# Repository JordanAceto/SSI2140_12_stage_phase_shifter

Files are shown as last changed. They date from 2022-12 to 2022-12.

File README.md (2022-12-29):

# SSI2140 Phase Shifter

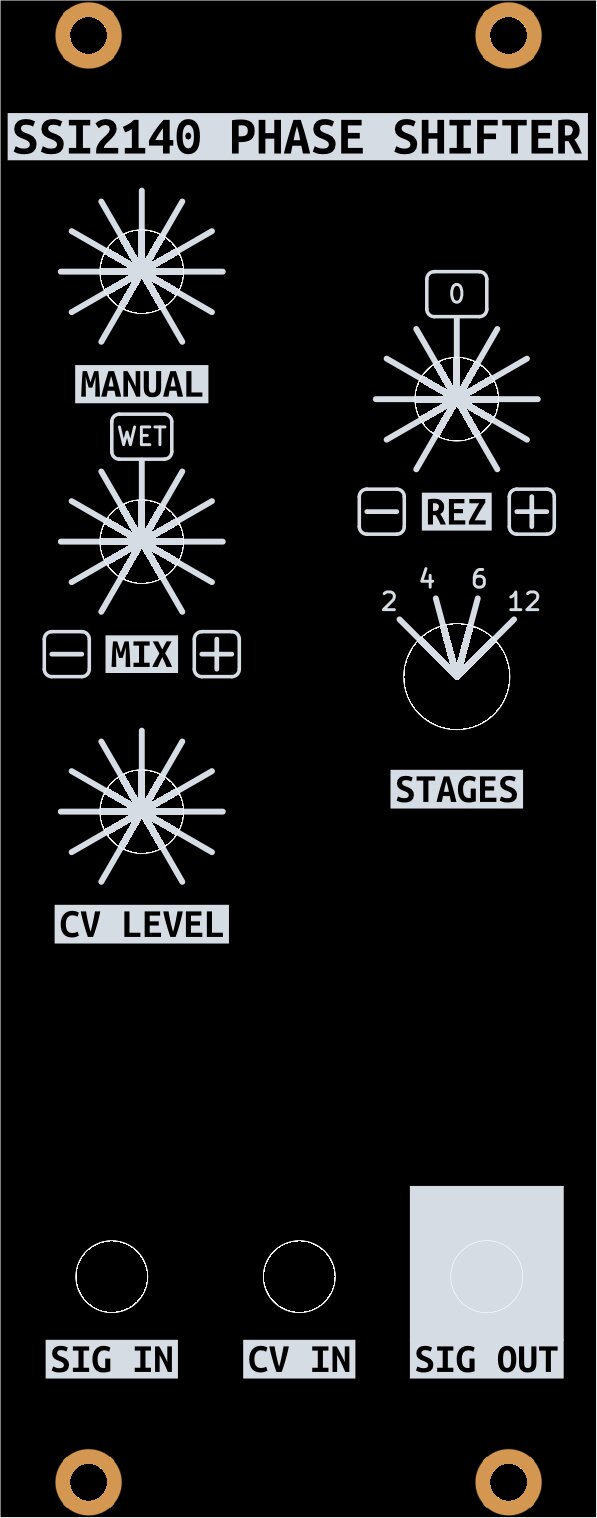
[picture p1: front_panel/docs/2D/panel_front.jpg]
front panel


---

## [SCHEMATIC](https://github.com/JordanAceto/SSI2140_12_stage_phase_shifter/blob/main/main_pcb/docs/SSI2140_phase_shifter-schematic.pdf)

---

### Features
- Eurorack 12 stage phase shifter
- Selectable number of stages (2, 4, 6, and 12)
- Positive and negative feedback
- Positive and negative wet/dry mix
- 1 attenuated CV input with approximately 1V/OCT response

---

## Status of the project:

Task | Status |
---------|--------------|
Schematic capture | &#9745;
PCB layout | &#9745;
Test build | &#9745;
Safe to order boards| &#9745;

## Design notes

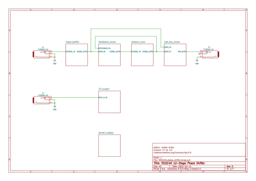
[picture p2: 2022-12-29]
main_pcb/docs/html_nav/images/cat_Schematic_SSI2140_phase_shifter-schematic.png

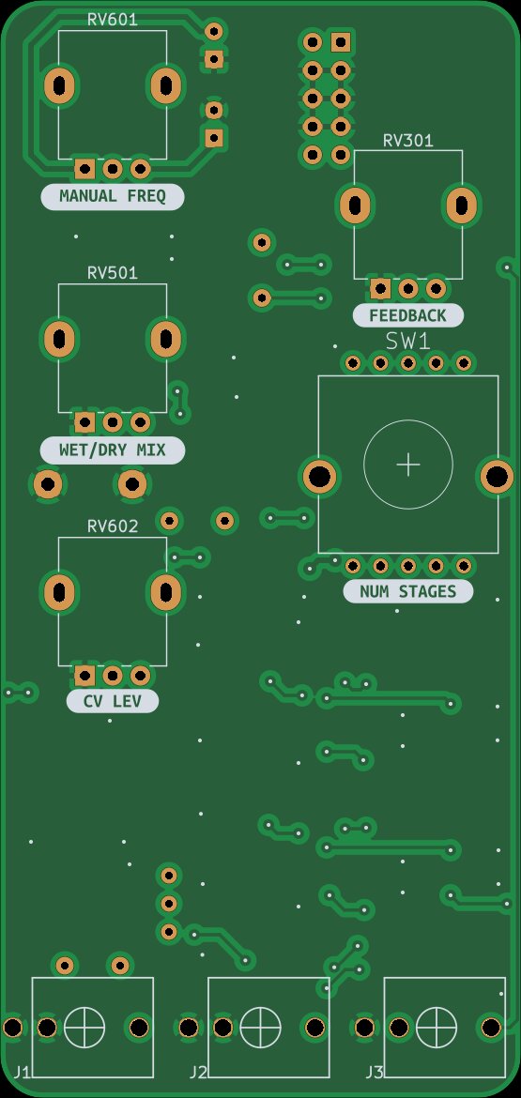
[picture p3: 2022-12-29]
main_pcb/docs/2D/SSI2140_phase_shifter-top.jpg

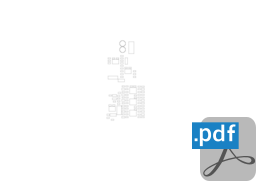
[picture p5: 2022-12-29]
main_pcb/docs/html_nav/images/cat_pdf_layers_SSI2140_phase_shifter-B_Courtyard.png

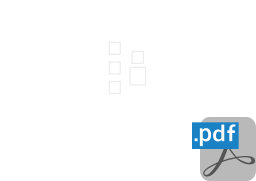
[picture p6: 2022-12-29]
main_pcb/docs/html_nav/images/cat_pdf_layers_SSI2140_phase_shifter-F_Courtyard.png

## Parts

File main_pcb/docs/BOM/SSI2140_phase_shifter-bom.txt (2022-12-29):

Row	Description	Part	References	Value	Footprint	Quantity Per PCB	Status	Datasheet
1	Unpolarized capacitor	C	C301 C303 C501 C503 C601	100p	C_0603_1608Metric	5	 	~
2	Unpolarized capacitor	C	C202	470p	C_0603_1608Metric	1	 	~
3	Unpolarized capacitor	C	C401 C402 C403 C404 C405 C406 C407 C408 C409 C410 C411 C412	1n C0G	C_0805_2012Metric	12	 	~
4	Unpolarized capacitor	C	C302	22n	C_Rect_L7.0mm_W2.5mm_P5.00mm	1	 	~
5	Unpolarized capacitor	C	C502	100n	C_Rect_L7.0mm_W2.5mm_P5.00mm	1	 	~
6	Unpolarized capacitor	C	C703 C704 C705 C706 C707 C708 C709 C710 C711 C712 C713 C714	100n	C_0603_1608Metric	12	 	~
7	Unpolarized capacitor	C	C201	220n	C_Rect_L7.0mm_W2.5mm_P5.00mm	1	 	~
8	Polarized capacitor	C_Polarized	C701 C702	10u	CP_Radial_D6.3mm_P2.50mm	2	 	~
9	Zener diode	D_Zener	D601 D602	5v1	D_SOD-123	2	 	~
10		PJ301M-12	J1 J2 J3	PJ301M-12	PJ301M-12	3	 	
11	Generic connector, double row, 02x05, odd/even pin numbering scheme (row 1 odd numbers, row 2 even numbers), script generated (kicad-library-utils/schlib/autogen/connector/)	Conn_02x05_Odd_Even	J5	power_entry	PinHeader_2x05_P2.54mm_Vertical	1	 	~
12	Resistor	R	R402 R405 R408 R411 R414 R417 R420 R423 R426 R429 R432 R435	200	R_0603_1608Metric	12	 	~
13	Resistor	R	R506	1k	R_0603_1608Metric	1	 	~
14	Resistor	R	R606	3k3	R_0603_1608Metric	1	 	~
15	Resistor	R	R201 R401 R403 R404 R406 R407 R409 R410 R412 R413 R415 R416 R418 R419 R421 R422 R424 R425 R427 R428 R430 R431 R433 R434 R436 R503	10k	R_0603_1608Metric	26	 	~
16	Resistor	R	R504 R607	15k	R_0603_1608Metric	2	 	~
17	Resistor	R	R202 R301 R302 R303 R304 R305 R501 R502 R505 R602 R605	100k	R_0603_1608Metric	11	 	~
18	Resistor	R	R603	270k	R_0603_1608Metric	1	 	~
19	Resistor	R	R604	1M	R_0603_1608Metric	1	 	~
20	Potentiometer	R_Potentiometer	RV301 RV501 RV601 RV602	100k c.d.	Potentiometer_Alpha_RD901F-40-00D_Single_Vertical	4	 	~
21	Trim-potentiometer	R_Potentiometer_Trim	RV603	100k	Potentiometer_Bourns_3296W_Vertical	1	 	~
22	3 rotary switches with 4 positions	SR1712F-0204	SW1	SR1712F-0204	SR1712F_rotary_switch	1	 	
23		SSI2140	U3 U4 U5	SSI2140	TSSOP-20_4.4x6.5mm_P0.65mm	3	 	
24	Dual Low-Noise JFET-Input Operational Amplifiers, DIP-8/SOIC-8	TL072	U1 U2 U6	TL072	SOIC-8_3.9x4.9mm_P1.27mm	3	 	http://www.ti.com/lit/ds/symlink/tl071.pdf

Project info:
Schematic:	SSI2140_phase_shifter
Variant:	default
Revision:	0
Date:	2022-10-11
KiCad Version:	6.0.5+dfsg-1~bpo11+1
Statistics:
Component Groups:	24
Component Count:	108 (87 SMD/ 15 THT)
Fitted Components:	108 (87 SMD/ 15 THT)
Number of PCBs:	1
Total Components:	108

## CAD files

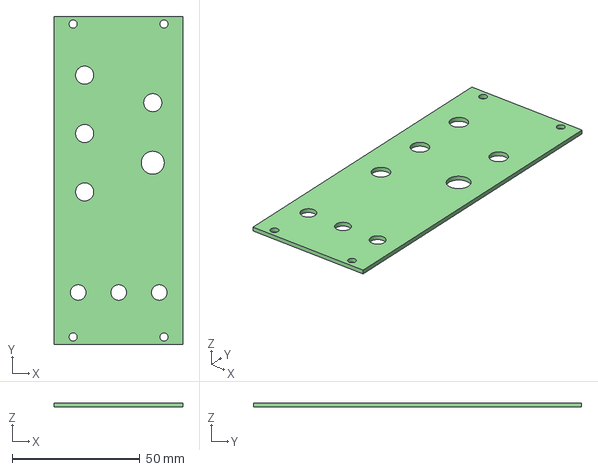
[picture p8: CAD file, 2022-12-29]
front_panel/docs/CAD/SSI2140_Phase_Shifter_front_panel-3D.step
50.5 x 128.5 x 1.60 mm

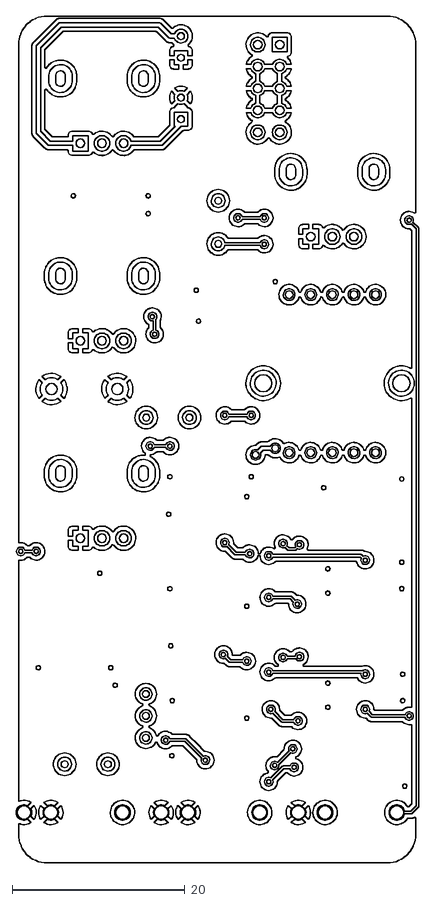
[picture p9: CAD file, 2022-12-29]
main_pcb/docs/CAD/SSI2140_phase_shifter-F_Cu.dxf
46.6 x 98.0

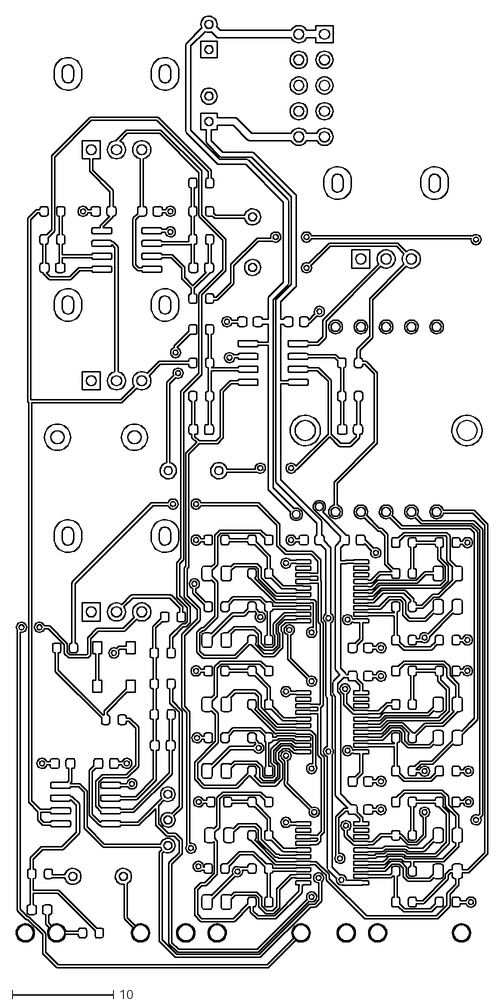
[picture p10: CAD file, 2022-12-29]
main_pcb/docs/CAD/SSI2140_phase_shifter-B_Cu.dxf
46.6 x 94.1

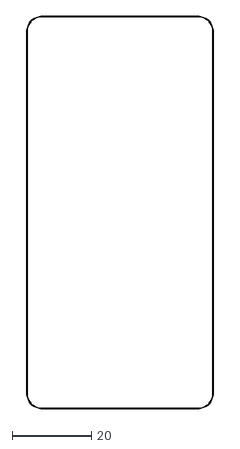
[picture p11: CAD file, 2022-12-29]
main_pcb/docs/CAD/SSI2140_phase_shifter-Edge_Cuts.dxf
47.0 x 99.1

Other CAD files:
main_pcb/docs/CAD/SSI2140_phase_shifter-B_Mask.dxf
main_pcb/docs/CAD/SSI2140_phase_shifter-B_Silkscreen.dxf
main_pcb/docs/CAD/SSI2140_phase_shifter-F_Mask.dxf
main_pcb/docs/CAD/SSI2140_phase_shifter-F_Silkscreen.dxf

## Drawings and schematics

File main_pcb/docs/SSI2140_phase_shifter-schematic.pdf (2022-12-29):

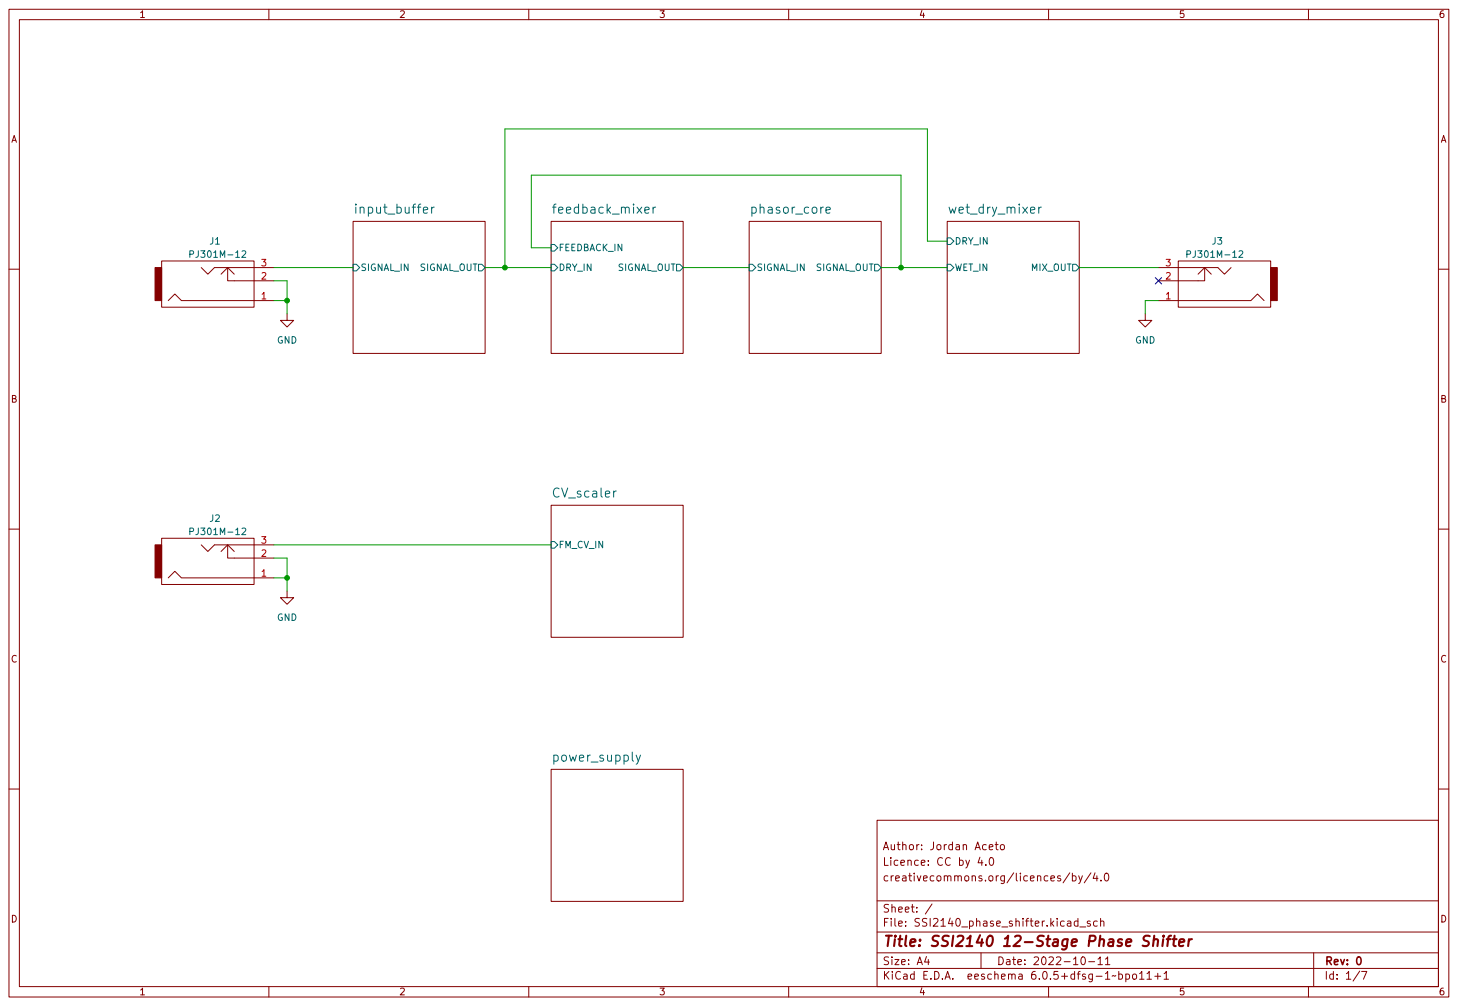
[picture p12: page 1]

Licence: CC by 4.0 Author: Jordan Aceto

File: SSI2140_phase_shifter.kicad_sch Sheet: / creativecommons.org/licences/by/4.0

Id: 1/7 Title: SSI2140 12-Stage Phase Shifter

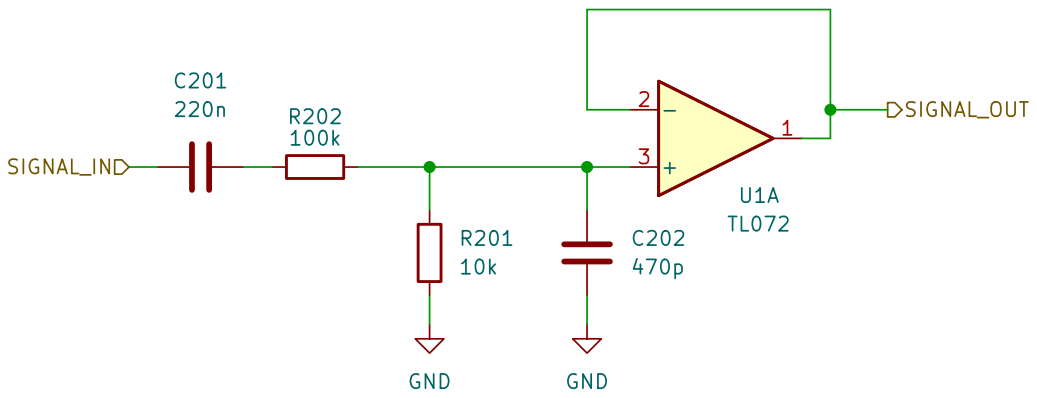
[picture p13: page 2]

Licence: CC by 4.0 Author: Jordan Aceto C201

creativecommons.org/licences/by/4.0

Sheet: /input_buffer/
File: input_buffer.kicad_sch
Id: 2/7 Title: SSI2140 12-Stage Phase Shifter

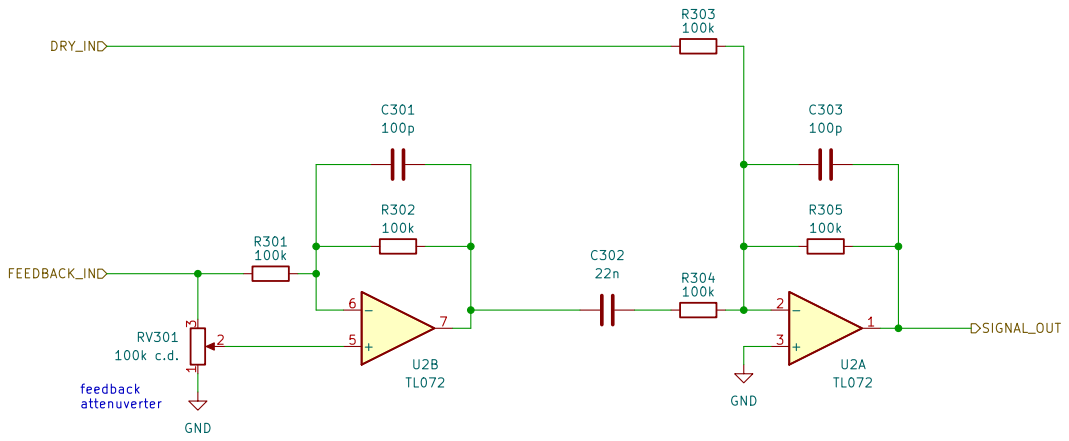
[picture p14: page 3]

Licence: CC by 4.0 Author: Jordan Aceto GND

creativecommons.org/licences/by/4.0

Sheet: /feedback_mixer/
File: feedback_mixer.kicad_sch
Id: 3/7 Title: SSI2140 12-Stage Phase Shifter

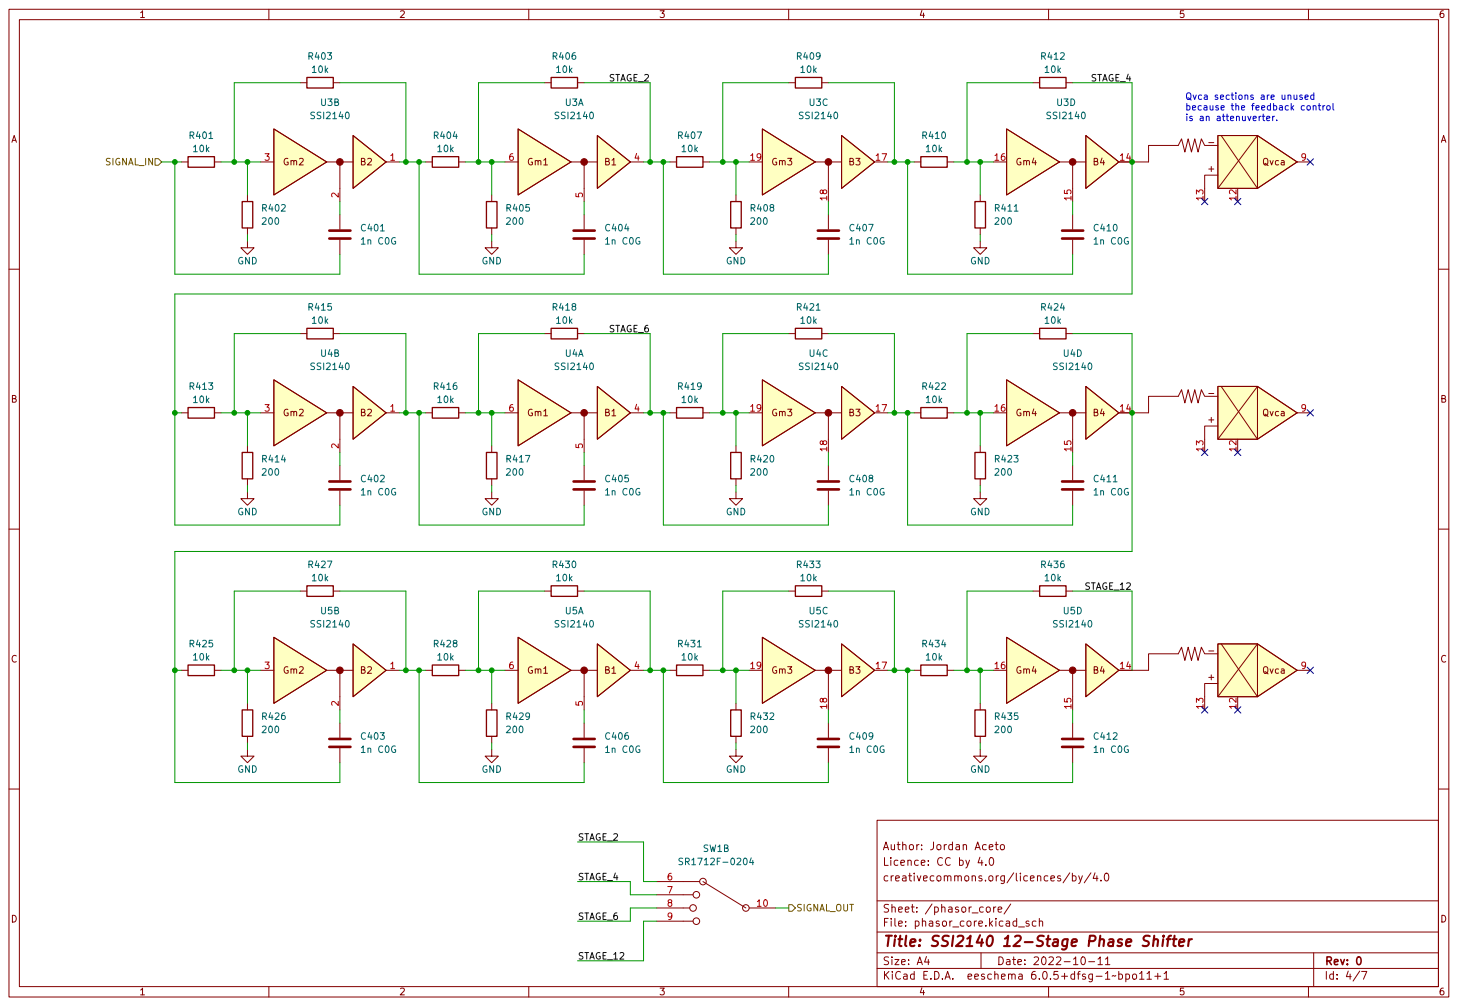
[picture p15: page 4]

because the feedback control
is an attenuverter.

Licence: CC by 4.0 Author: Jordan Aceto GND GND

creativecommons.org/licences/by/4.0

Sheet: /phasor_core/
File: phasor_core.kicad_sch
Id: 4/7 Title: SSI2140 12-Stage Phase Shifter

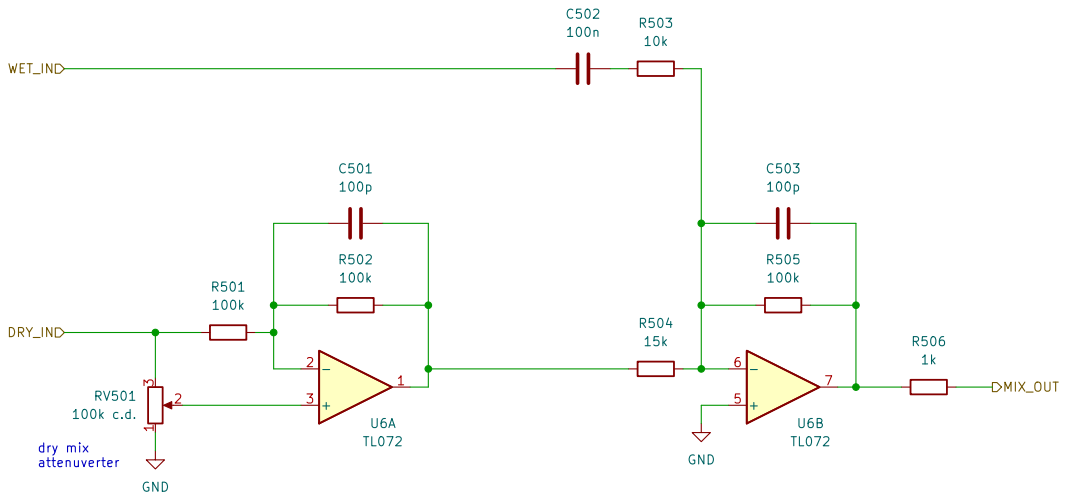
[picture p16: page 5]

Licence: CC by 4.0 Author: Jordan Aceto GND

creativecommons.org/licences/by/4.0

Sheet: /wet_dry_mixer/
File: wet_dry_mixer.kicad_sch
Id: 5/7 Title: SSI2140 12-Stage Phase Shifter

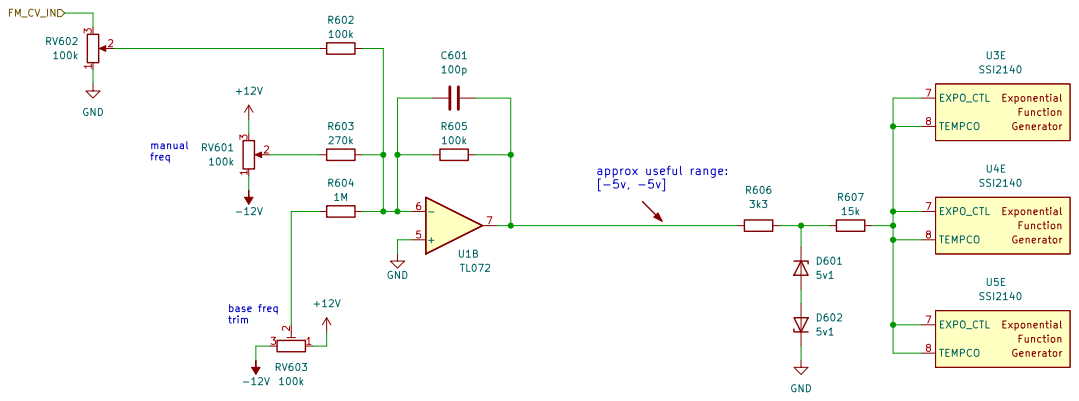
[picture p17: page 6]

creativecommons.org/licences/by/4.0

Sheet: /CV_scaler/
File: CV_scalers.kicad_sch
Id: 6/7 Title: SSI2140 12-Stage Phase Shifter

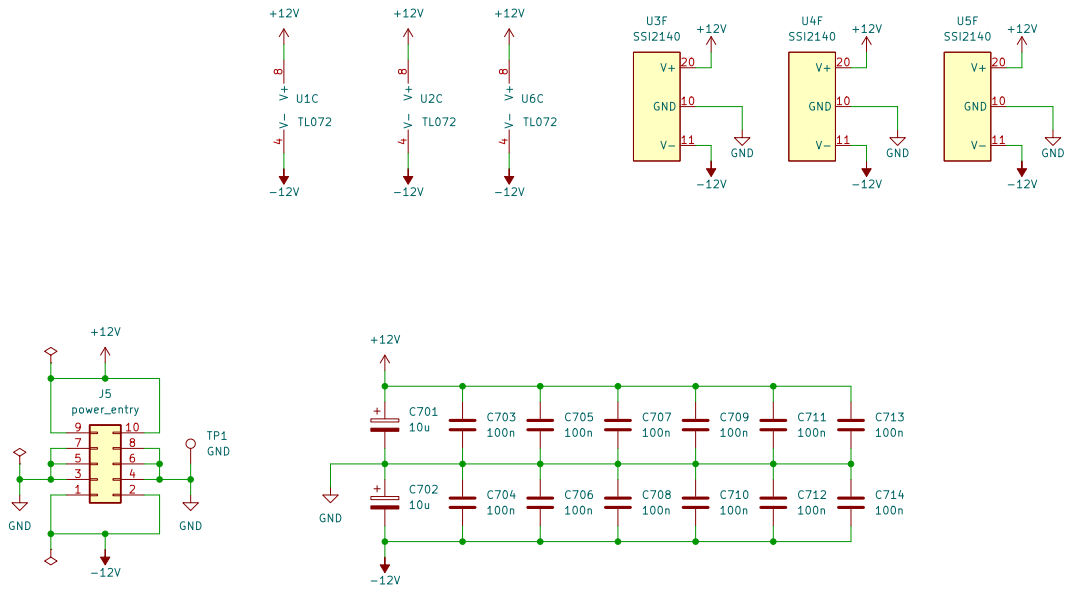
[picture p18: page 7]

Licence: CC by 4.0 Author: Jordan Aceto

creativecommons.org/licences/by/4.0

Sheet: /power_supply/
File: power_supply.kicad_sch
Id: 7/7 Title: SSI2140 12-Stage Phase Shifter

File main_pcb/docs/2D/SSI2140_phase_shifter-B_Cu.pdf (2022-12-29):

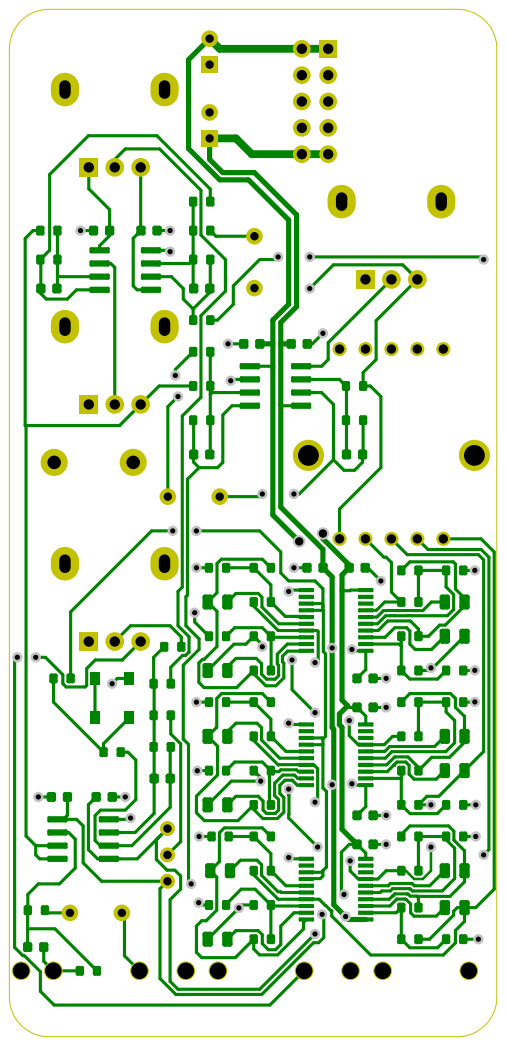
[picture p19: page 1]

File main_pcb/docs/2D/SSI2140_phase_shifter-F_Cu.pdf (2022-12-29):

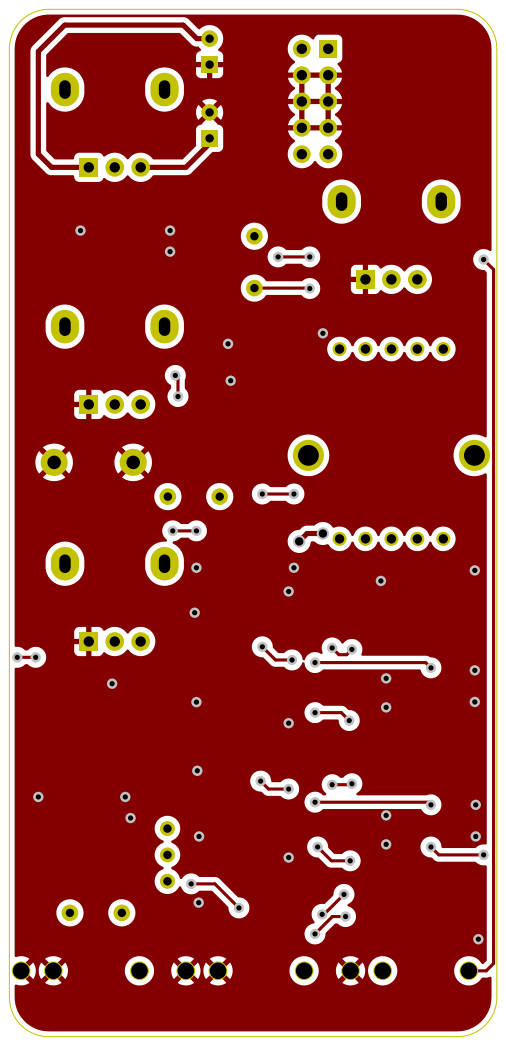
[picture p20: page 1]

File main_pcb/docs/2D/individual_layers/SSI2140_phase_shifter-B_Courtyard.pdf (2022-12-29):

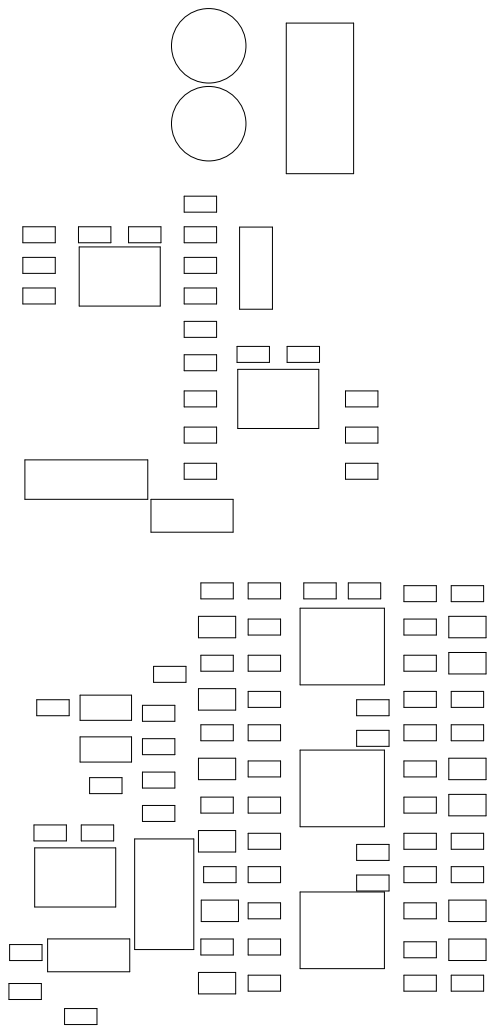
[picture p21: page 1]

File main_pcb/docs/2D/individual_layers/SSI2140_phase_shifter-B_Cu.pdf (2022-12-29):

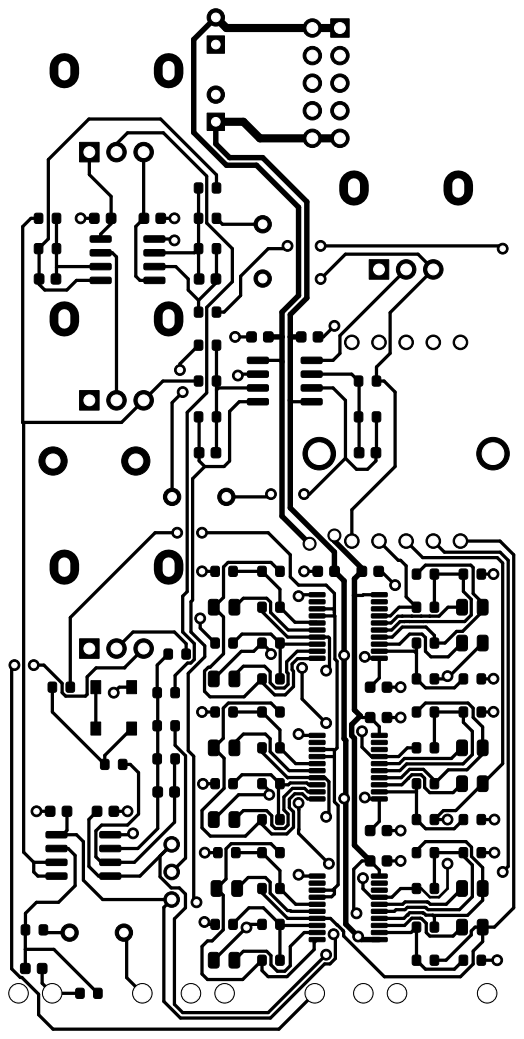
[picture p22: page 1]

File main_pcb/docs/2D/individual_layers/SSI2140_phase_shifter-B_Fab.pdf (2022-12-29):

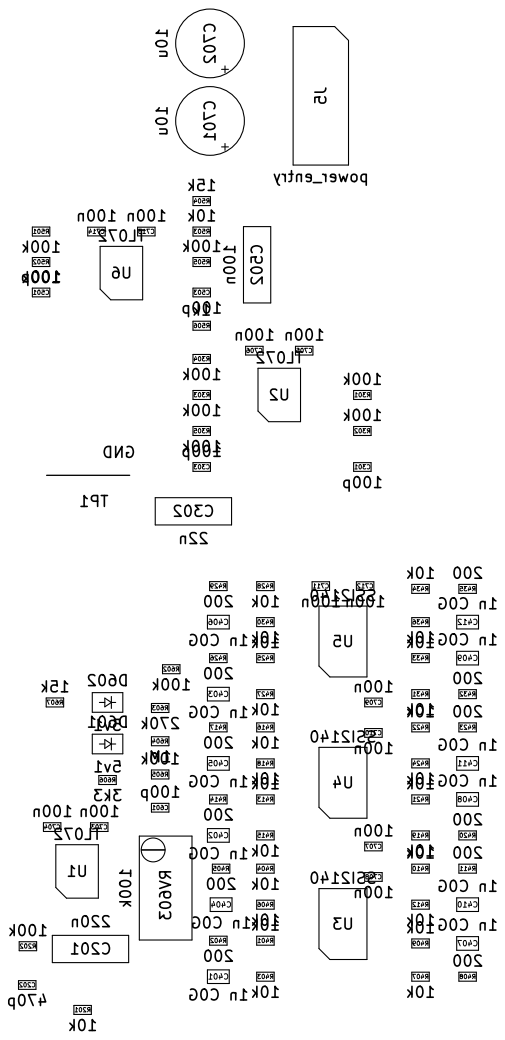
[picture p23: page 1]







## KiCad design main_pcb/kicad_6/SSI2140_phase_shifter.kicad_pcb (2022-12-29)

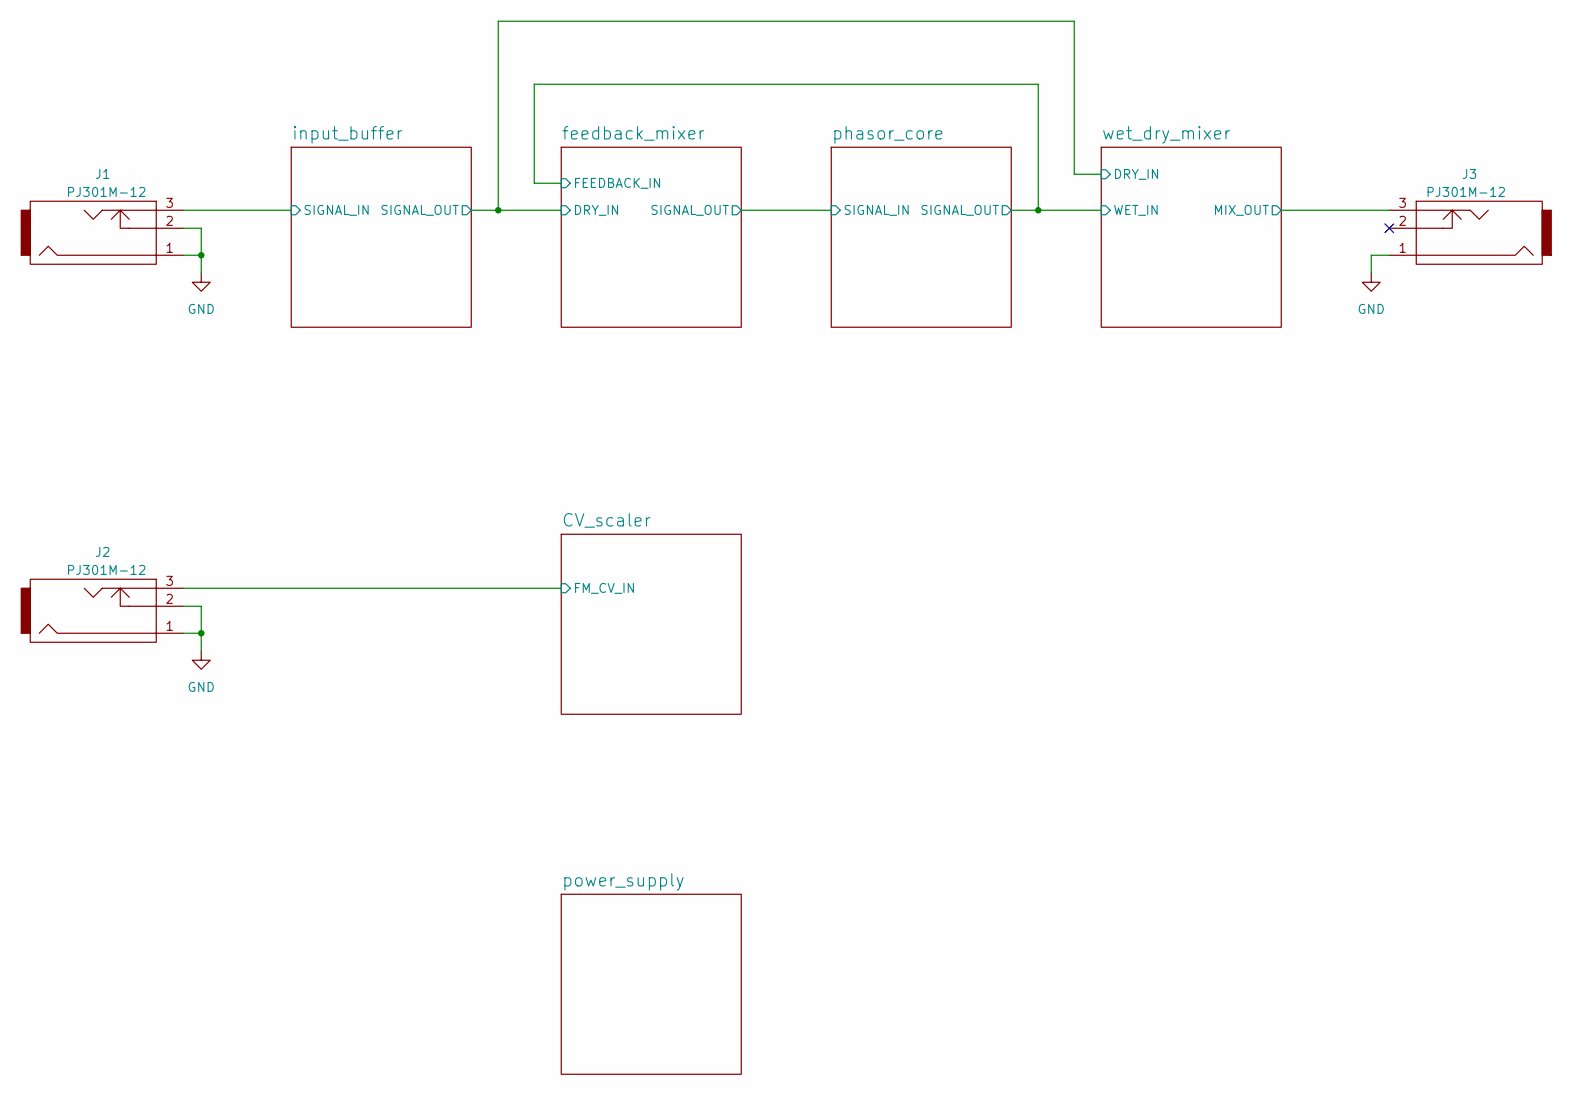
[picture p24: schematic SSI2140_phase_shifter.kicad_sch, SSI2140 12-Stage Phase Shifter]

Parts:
J1, J2, J3: PJ301M-12

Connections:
/CV_scaler/FM_CV_IN: J2.3; also elsewhere on the board
/input_buffer/SIGNAL_IN: J1.3; also elsewhere on the board
/wet_dry_mixer/MIX_OUT: J3.3; also elsewhere on the board
GND: J1.1, J1.2, J2.1, J2.2, J3.1; also elsewhere on the board

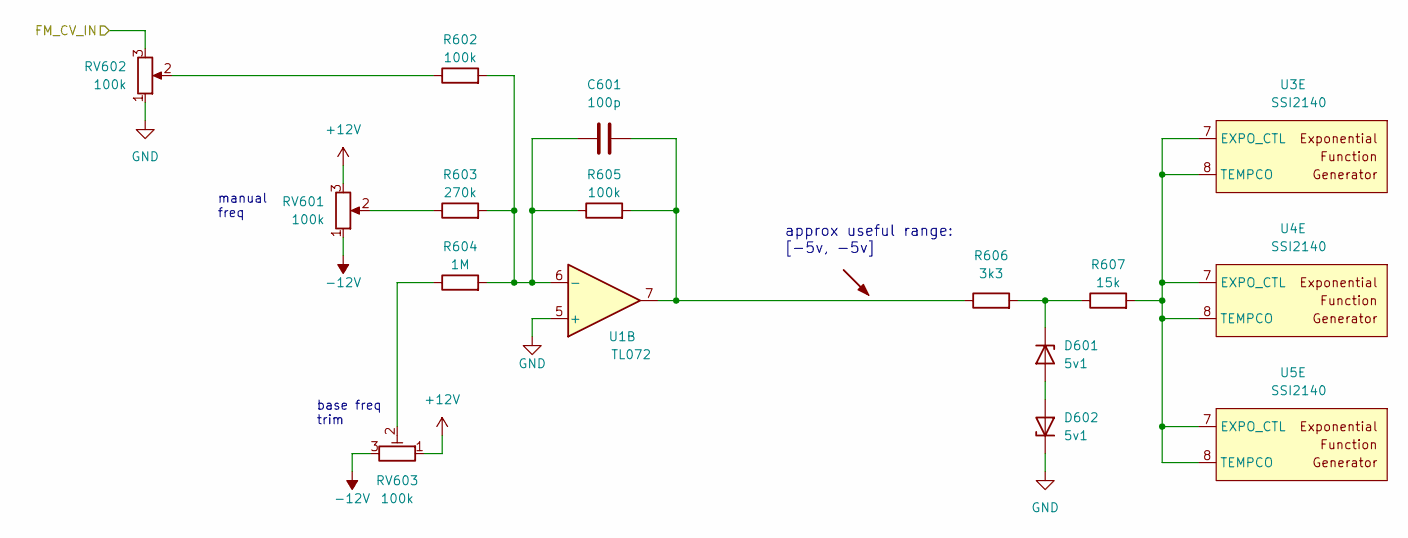
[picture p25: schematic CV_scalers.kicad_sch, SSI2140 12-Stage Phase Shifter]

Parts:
C601: 100p; C_0603_1608Metric
D601, D602: 5v1; D_SOD-123
R602, R605: 100k; R_0603_1608Metric
R603: 270k; R_0603_1608Metric
R604: 1M; R_0603_1608Metric
R606: 3k3; R_0603_1608Metric
R607: 15k; R_0603_1608Metric
RV601, RV602: 100k; Potentiometer_Alpha_RD901F-40-00D_Single_Vertical
RV603: 100k; Potentiometer_Bourns_3296W_Vertical
U1: TL072; SOIC-8_3.9x4.9mm_P1.27mm
U3, U4, U5: SSI2140; TSSOP-20_4.4x6.5mm_P0.65mm

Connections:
+12V: RV601.3, RV603.1; also elsewhere on the board
-12V: RV601.1, RV603.3; also elsewhere on the board
/CV_scaler/FM_CV_IN: RV602.3; also elsewhere on the board
GND: D602.1 (K), RV602.1, U1.5 (+); also elsewhere on the board
unnamed: C601.1, R602.2, R603.2, R604.2, R605.1, U1.6 (-)
unnamed: C601.2, R605.2, R606.1, U1.7
unnamed: D601.1 (K), R606.2, R607.1
unnamed: D601.2 (A), D602.2 (A)
unnamed: R602.1, RV602.2
unnamed: R603.1, RV601.2
unnamed: R604.1, RV603.2
unnamed: R607.2, U3.7 (EXPO_CTL), U3.8 (TEMPCO), U4.7 (EXPO_CTL), U4.8 (TEMPCO), U5.7 (EXPO_CTL), U5.8 (TEMPCO)

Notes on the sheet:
base freq trim
manual freq
approx useful range: [-5v, -5v]

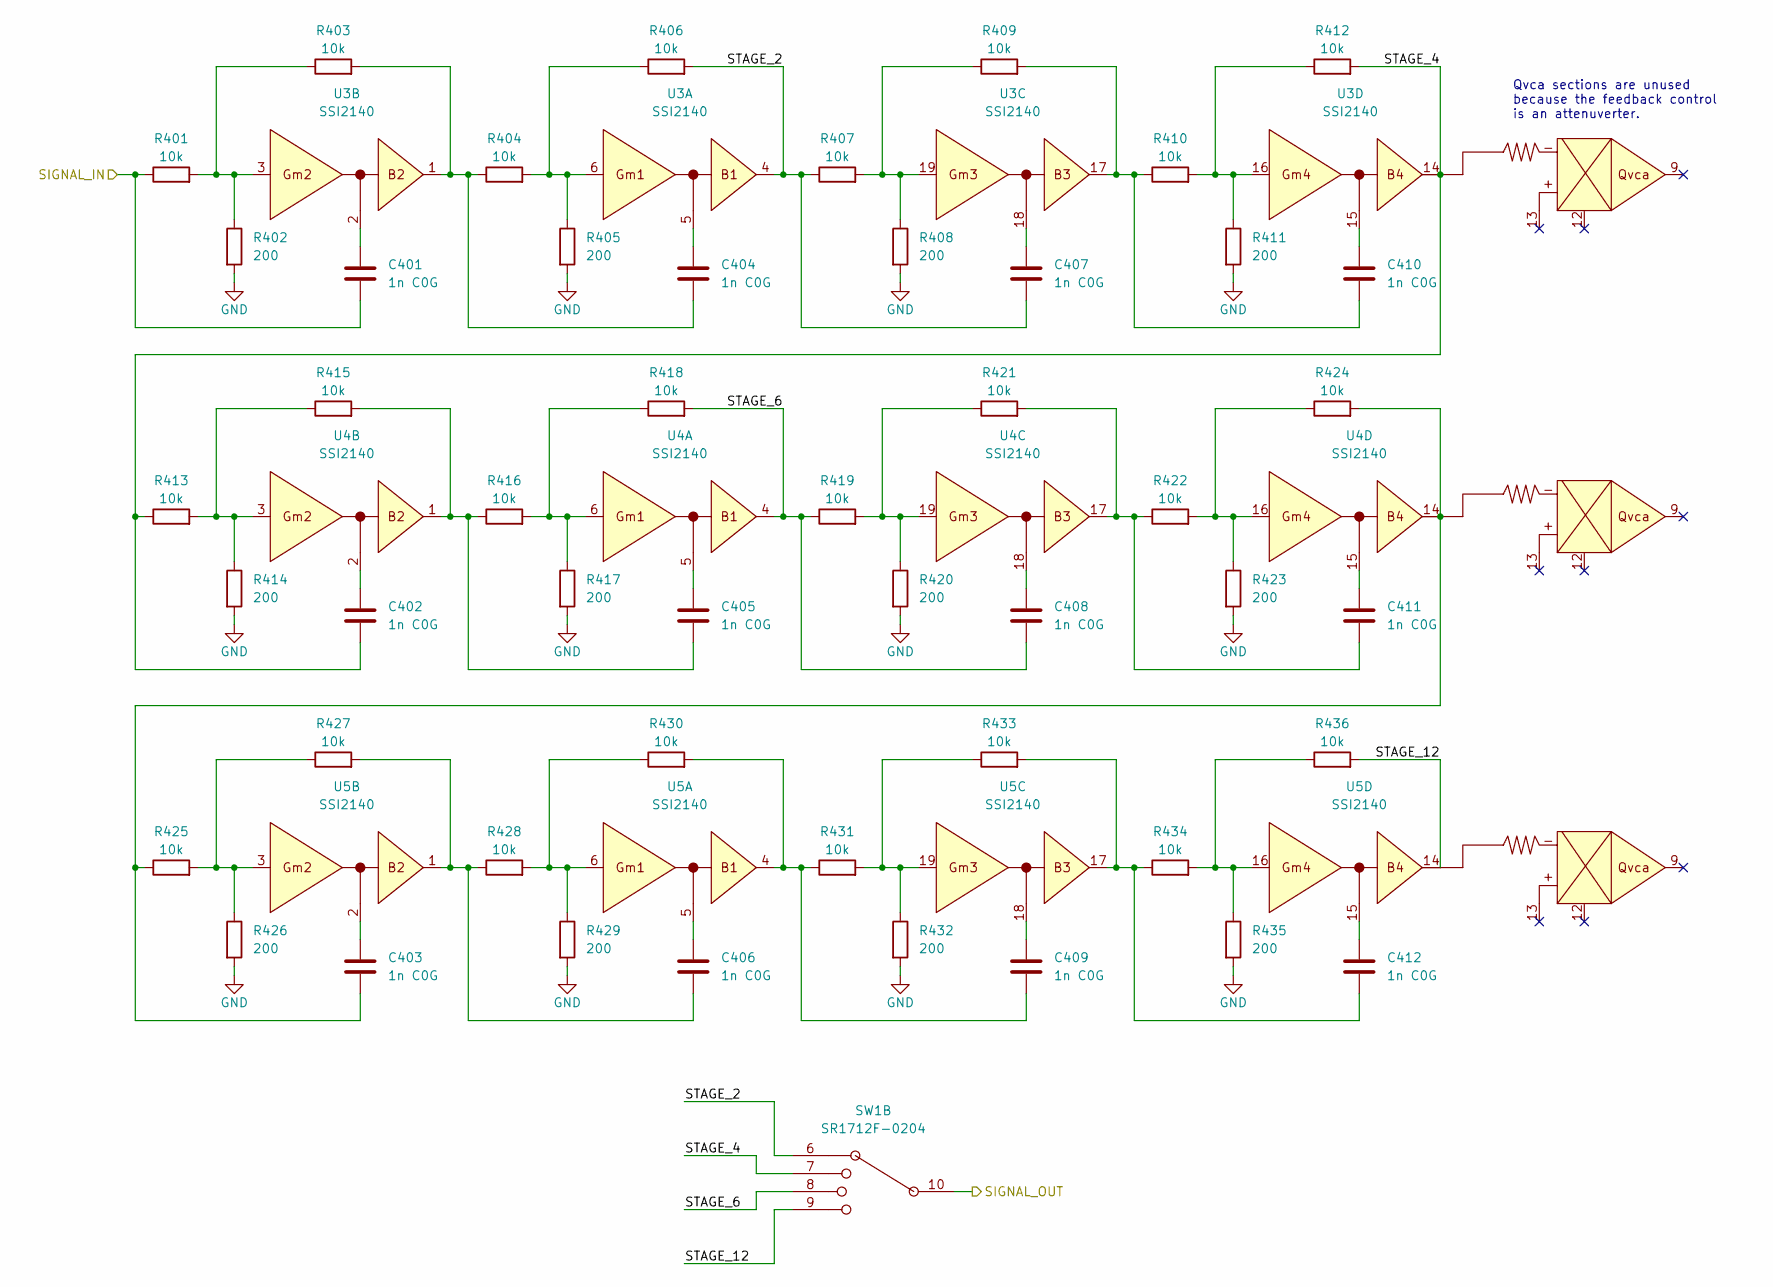
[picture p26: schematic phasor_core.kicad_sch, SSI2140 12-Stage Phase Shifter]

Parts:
C401, C402, C403, C404, C405, C406, C407, C408, C409, C410, C411, C412: 1n C0G; C_0805_2012Metric
R401, R403, R404, R406, R407, R409, R410, R412, R413, R415, R416, R418, R419, R421, R422, R424, R425, R427, R428, R430, R431, R433, R434, R436: 10k; R_0603_1608Metric
R402, R405, R408, R411, R414, R417, R420, R423, R426, R429, R432, R435: 200; R_0603_1608Metric
SW1: SR1712F-0204; SR1712F_rotary_switch
U3, U4, U5: SSI2140; TSSOP-20_4.4x6.5mm_P0.65mm

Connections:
/feedback_mixer/FEEDBACK_IN: SW1.10; also elsewhere on the board
/feedback_mixer/SIGNAL_OUT: C401.2, R401.1; also elsewhere on the board
/phasor_core/STAGE_2: C407.2, R406.2, R407.1, SW1.6, U3.4
/phasor_core/STAGE_4: C402.2, R412.2, R413.1, SW1.7, U3.14
/phasor_core/STAGE_6: C408.2, R418.2, R419.1, SW1.8, U4.4
/phasor_core/STAGE_12: R436.2, SW1.9, U5.14
GND: R402.2, R405.2, R408.2, R411.2, R414.2, R417.2, R420.2, R423.2, R426.2, R429.2, R432.2, R435.2; also elsewhere on the board
unnamed: C401.1, U3.2
unnamed: C402.1, U4.2
unnamed: C403.1, U5.2
unnamed: C403.2, R424.2, R425.1, U4.14
unnamed: C404.1, U3.5
unnamed: C404.2, R403.2, R404.1, U3.1
unnamed: C405.1, U4.5
unnamed: C405.2, R415.2, R416.1, U4.1
unnamed: C406.1, U5.5
unnamed: C406.2, R427.2, R428.1, U5.1
unnamed: C407.1, U3.18
unnamed: C408.1, U4.18
unnamed: C409.1, U5.18
unnamed: C409.2, R430.2, R431.1, U5.4
unnamed: C410.1, U3.15
unnamed: C410.2, R409.2, R410.1, U3.17
unnamed: C411.1, U4.15
unnamed: C411.2, R421.2, R422.1, U4.17
unnamed: C412.1, U5.15
unnamed: C412.2, R433.2, R434.1, U5.17
unnamed: R401.2, R402.1, R403.1, U3.3
unnamed: R404.2, R405.1, R406.1, U3.6
unnamed: R407.2, R408.1, R409.1, U3.19
unnamed: R410.2, R411.1, R412.1, U3.16
unnamed: R413.2, R414.1, R415.1, U4.3
unnamed: R416.2, R417.1, R418.1, U4.6
unnamed: R419.2, R420.1, R421.1, U4.19
unnamed: R422.2, R423.1, R424.1, U4.16
unnamed: R425.2, R426.1, R427.1, U5.3
unnamed: R428.2, R429.1, R430.1, U5.6
unnamed: R431.2, R432.1, R433.1, U5.19
unnamed: R434.2, R435.1, R436.1, U5.16

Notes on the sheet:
Qvca sections are unused because the feedback control is an attenuverter.

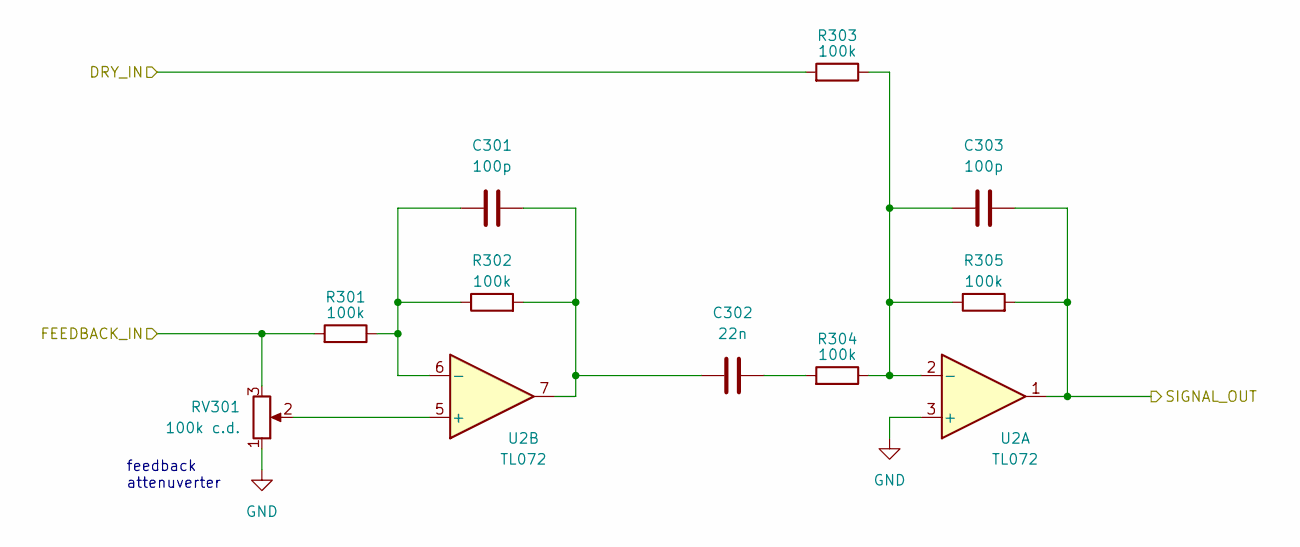
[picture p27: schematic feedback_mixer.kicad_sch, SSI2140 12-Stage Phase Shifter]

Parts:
C301, C303: 100p; C_0603_1608Metric
C302: 22n; C_Rect_L7.0mm_W2.5mm_P5.00mm
R301, R302, R303, R304, R305: 100k; R_0603_1608Metric
RV301: 100k c.d.; Potentiometer_Alpha_RD901F-40-00D_Single_Vertical
U2: TL072; SOIC-8_3.9x4.9mm_P1.27mm

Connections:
/feedback_mixer/DRY_IN: R303.2; also elsewhere on the board
/feedback_mixer/FEEDBACK_IN: R301.2, RV301.3; also elsewhere on the board
/feedback_mixer/SIGNAL_OUT: C303.1, R305.2, U2.1; also elsewhere on the board
GND: RV301.1, U2.3 (+); also elsewhere on the board
unnamed: C301.1, C302.1, R302.2, U2.7
unnamed: C301.2, R301.1, R302.1, U2.6 (-)
unnamed: C302.2, R304.2
unnamed: C303.2, R303.1, R304.1, R305.1, U2.2 (-)
unnamed: RV301.2, U2.5 (+)

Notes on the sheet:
feedback attenuverter

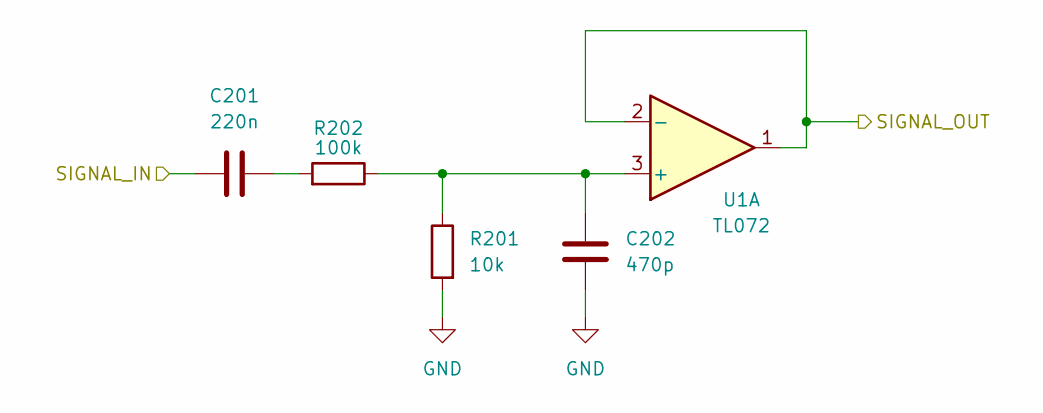
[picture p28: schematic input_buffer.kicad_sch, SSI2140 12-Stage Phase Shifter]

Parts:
C201: 220n; C_Rect_L7.0mm_W2.5mm_P5.00mm
C202: 470p; C_0603_1608Metric
R201: 10k; R_0603_1608Metric
R202: 100k; R_0603_1608Metric
U1: TL072; SOIC-8_3.9x4.9mm_P1.27mm

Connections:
/feedback_mixer/DRY_IN: U1.1, U1.2 (-); also elsewhere on the board
/input_buffer/SIGNAL_IN: C201.2; also elsewhere on the board
GND: C202.1, R201.2; also elsewhere on the board
unnamed: C201.1, R202.2
unnamed: C202.2, R201.1, R202.1, U1.3 (+)

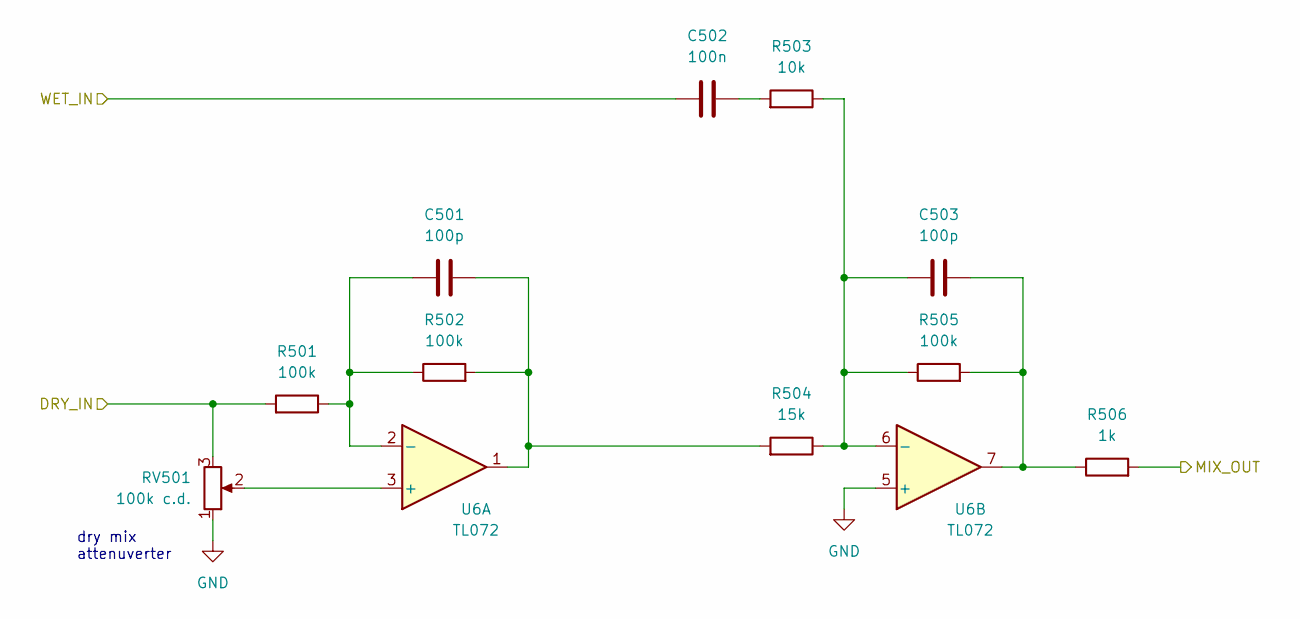
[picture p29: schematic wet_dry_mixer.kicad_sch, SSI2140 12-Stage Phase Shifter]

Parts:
C501, C503: 100p; C_0603_1608Metric
C502: 100n; C_Rect_L7.0mm_W2.5mm_P5.00mm
R501, R502, R505: 100k; R_0603_1608Metric
R503: 10k; R_0603_1608Metric
R504: 15k; R_0603_1608Metric
R506: 1k; R_0603_1608Metric
RV501: 100k c.d.; Potentiometer_Alpha_RD901F-40-00D_Single_Vertical
U6: TL072; SOIC-8_3.9x4.9mm_P1.27mm

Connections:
/feedback_mixer/DRY_IN: R501.2, RV501.3; also elsewhere on the board
/feedback_mixer/FEEDBACK_IN: C502.1; also elsewhere on the board
/wet_dry_mixer/MIX_OUT: R506.2; also elsewhere on the board
GND: RV501.1, U6.5 (+); also elsewhere on the board
unnamed: C501.1, R502.2, R504.2, U6.1
unnamed: C501.2, R501.1, R502.1, U6.2 (-)
unnamed: C502.2, R503.2
unnamed: C503.1, R505.2, R506.1, U6.7
unnamed: C503.2, R503.1, R504.1, R505.1, U6.6 (-)
unnamed: RV501.2, U6.3 (+)

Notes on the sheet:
dry mix attenuverter

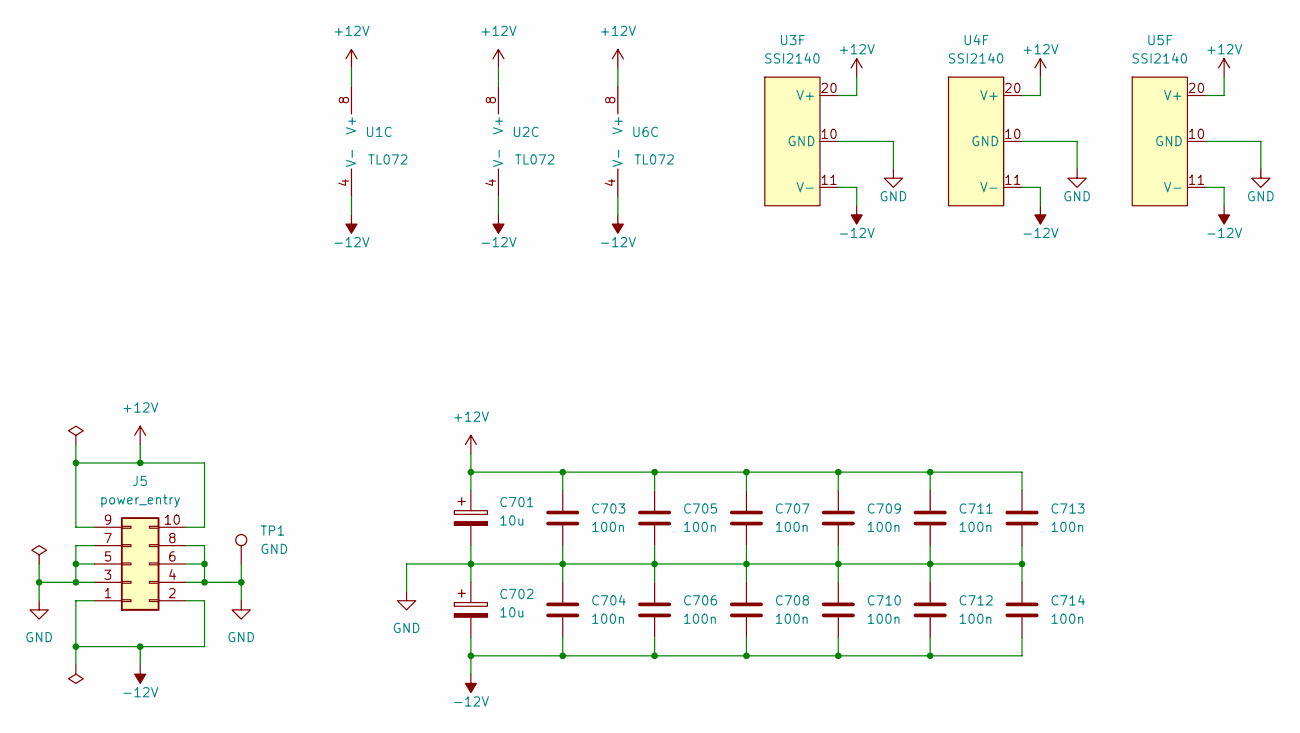
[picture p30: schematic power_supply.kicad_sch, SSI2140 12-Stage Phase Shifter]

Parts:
C701, C702: 10u; CP_Radial_D6.3mm_P2.50mm
C703, C704, C705, C706, C707, C708, C709, C710, C711, C712, C713, C714: 100n; C_0603_1608Metric
J5: power_entry; PinHeader_2x05_P2.54mm_Vertical
TP1: GND; TestPoint_Bridge_Pitch7.62mm_Drill1.3mm
U1, U2, U6: TL072; SOIC-8_3.9x4.9mm_P1.27mm
U3, U4, U5: SSI2140; TSSOP-20_4.4x6.5mm_P0.65mm

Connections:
+12V: C701.1, C703.1, C705.1, C707.1, C709.1, C711.1, C713.1, J5.9, J5.10, U1.8 (V+), U2.8 (V+), U3.20 (V+), U4.20 (V+), U5.20 (V+), U6.8 (V+); also elsewhere on the board
-12V: C702.2, C704.2, C706.2, C708.2, C710.2, C712.2, C714.2, J5.1, J5.2, U1.4 (V-), U2.4 (V-), U3.11 (V-), U4.11 (V-), U5.11 (V-), U6.4 (V-); also elsewhere on the board
GND: C701.2, C702.1, C703.2, C704.1, C705.2, C706.1, C707.2, C708.1, C709.2, C710.1, C711.2, C712.1, C713.2, C714.1, J5.3, J5.4, J5.5, J5.6, J5.7, J5.8, TP1.1, U3.10 (GND), U4.10 (GND), U5.10 (GND); also elsewhere on the board

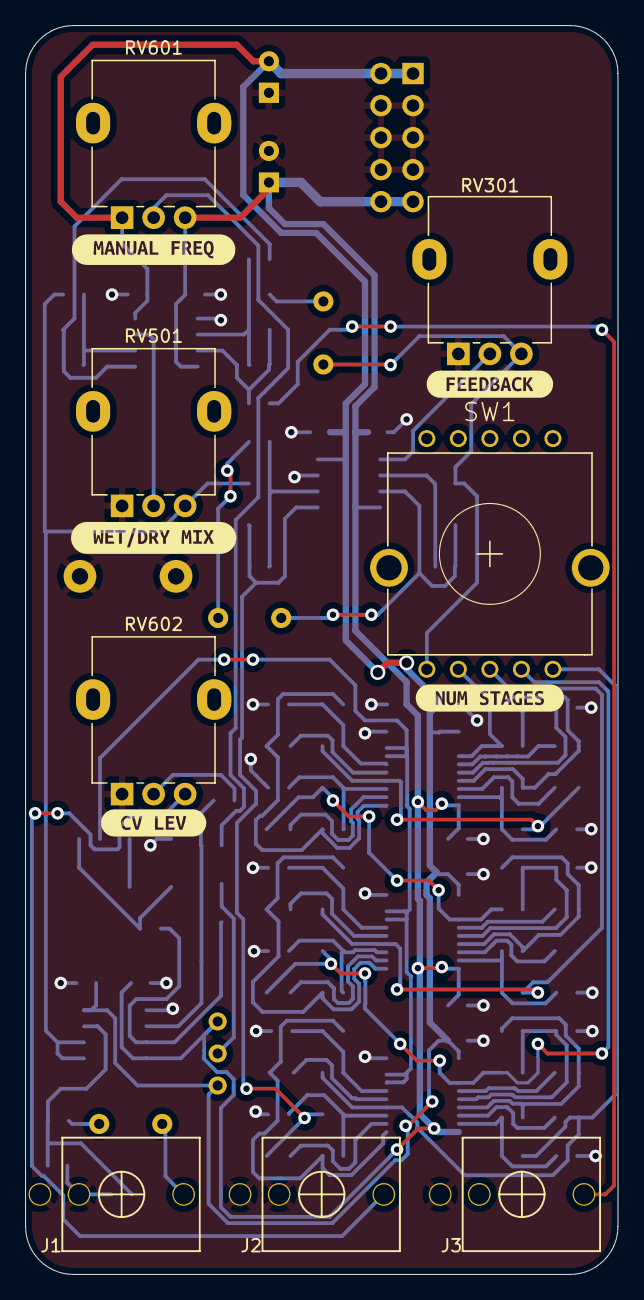
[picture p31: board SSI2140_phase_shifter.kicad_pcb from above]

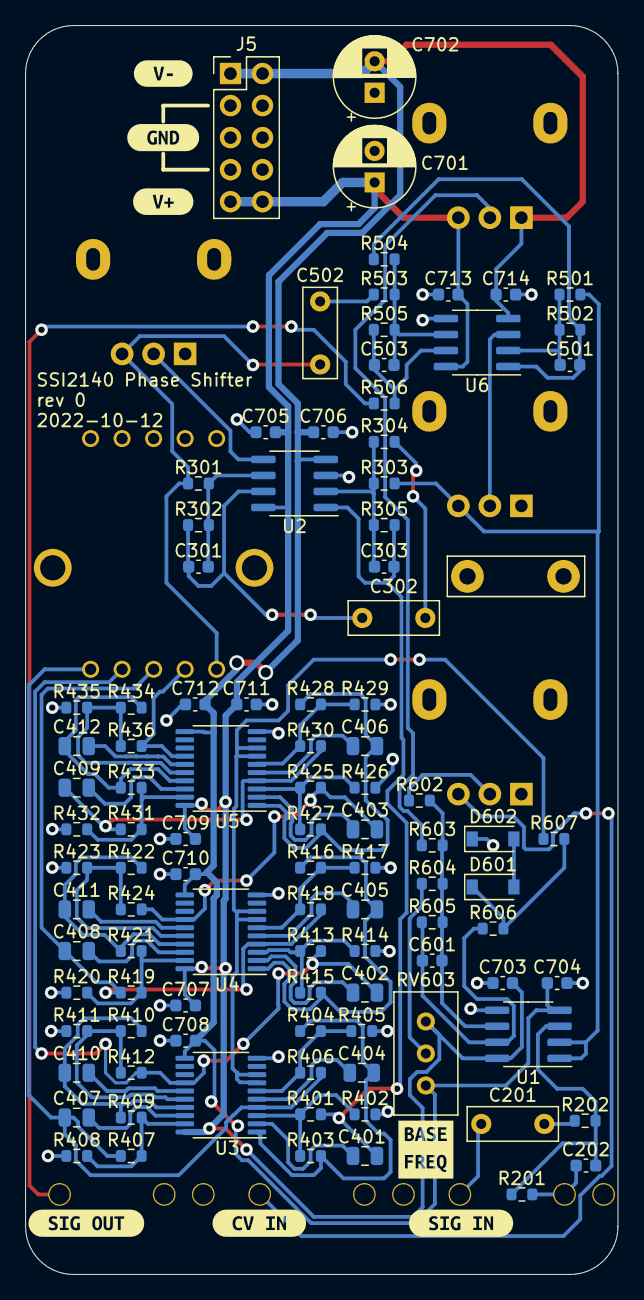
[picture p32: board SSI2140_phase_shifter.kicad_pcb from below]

Board: 2 copper layers, 47.0 x 99.1 mm, 121 parts (108 on the bottom side), 66 nets.

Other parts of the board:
kibuzzard-6346B9B0: G***; kibuzzard-6346B9B0
kibuzzard-6346B9BA: G***; kibuzzard-6346B9BA
kibuzzard-6346B9C8: G***; kibuzzard-6346B9C8
kibuzzard-6346BA4D: G***; kibuzzard-6346BA4D
kibuzzard-6346BA5C: G***; kibuzzard-6346BA5C
kibuzzard-6346BA18: G***; kibuzzard-6346BA18
kibuzzard-6346BA34: G***; kibuzzard-6346BA34
kibuzzard-6346BB8C: G***; kibuzzard-6346BB8C
kibuzzard-6346BB9C: G***; kibuzzard-6346BB9C
kibuzzard-6346BBAC: G***; kibuzzard-6346BBAC
kibuzzard-6346BBB6: G***; kibuzzard-6346BBB6
kibuzzard-6346BBC8: G***; kibuzzard-6346BBC8

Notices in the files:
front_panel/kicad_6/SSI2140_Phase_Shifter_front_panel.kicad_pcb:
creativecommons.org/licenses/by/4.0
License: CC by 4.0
